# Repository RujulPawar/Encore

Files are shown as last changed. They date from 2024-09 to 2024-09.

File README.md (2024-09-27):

## **Buck Converter Design and Simulation**

### **Team Information**
- **Team Leader**:
  - Rujul Pawar
- **Team Members**: 
  - Samar Mhetre

### **Project Overview**
This repository is for the **Encore Pre-qualifier Challenge 2024-25**, focusing on designing a **buck converter**. The main objectives of this project are:
- **Input Voltage**: 24V DC (1A max)
- **Output Voltage**: 5V DC
- **Target Efficiency**: 90% or higher

### **Repository Structure**
- **Datasheets/**: Relevant component datasheets.
- **KicadFiles/**: Schematic and PCB layout files created using **KiCad**.
- **BuckConverterLtspice.asc**: LTSpice simulation file for testing the design.
- **EncoreBom.csv**: Bill of Materials (BoM) detailing components used.

### **Simulation and PCB Design**
- **Simulation**: To verify the circuit, open and run `BuckConverterLtspice.asc` in **LTSpice**.
- **PCB Layout**: A dual-layer PCB design with a maximum size of **10cm x 5cm**, created using **KiCad**.

### **References**
- [Texas Instruments SLVA477B Design Guide](https://www.ti.com/lit/an/slva477b/slva477b.pdf)

---

This document serves as a concise guide to the contents and structure of this repository. For further details, explore the files and links provided.

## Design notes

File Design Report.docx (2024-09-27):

Design Report

1) Given data:
- V(out) = 5V
- V(in) = 24V
- I(in) = 1A
- Therefore, calculating P(in) = V x I

= 24W

- Required efficiency = 90%
- Therefore, P(out) = 0.9 x 24

= 21.6W

- Calculating output current, I(out) = P(out)/V = 4.32A
2) Assumptions:
- The switching frequency, fs, of a buck converter tends to be higher for minimizing the L and C values. On the other hand, the efficiency of the converter is inversely proportional to the fs, therefore we have chosen a switching frequency fs = 100kHz.
- In an ideal scenario, we assume average voltage across inductor to be zero.
- Similarly, we assume average current through capacitor to be zero.

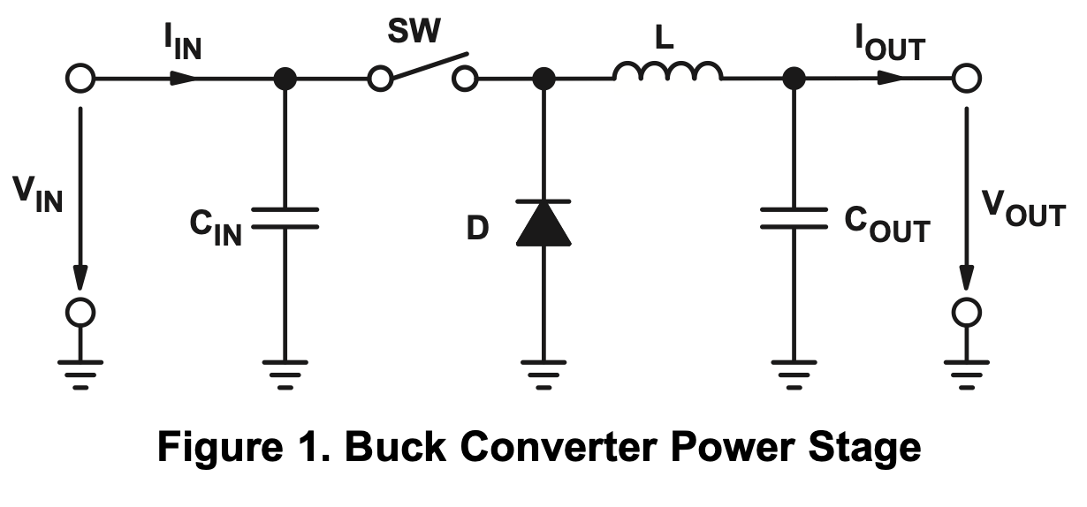
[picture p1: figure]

3) Calculations:
- Based on the above given data and the assumptions made for designing, we have calculated the following values:
  - D = (Vout)/(Vin) = 21%
  - ΔIl = 15% of I(out) = 0.648A
  - Lcritical = ((Vin – Vout) × D)/(2 × Ilb) = 4.4µH

Where Ilb is boundary current through Inductor, which is 4.32A in our case(considering the input current and voltage as 24V)

  - Lripple = (Vin × D × (1-D))/(fs × Il) = 60µH
  - We have to consider the value of L greater than Lripple and Lcritical. Therefore, we have considered L = 75µH.
  - Rpeak = (Vout)/(Iout)=1.15
  - ΔVc = 2% of Vo(peak) … as given in the statement

= 0.1V

  - C = (Vin × D × (1-D))/(8 × fs^2 × Vc) = 6.5µF.
4) Generating 21% duty cycle
- We have used IC 555 to generate the 20% duty cycle for PWM switching.
- Since the astable mode does not allow duty cycle < 50%, we have generated 79% duty cycle using the IC 555 and then used a combination of MOSFETs to reverse the Ton and Toff for the converter circuit, ultimately giving us a Power stage duty cycle of 21% for the converter circuit.
- Calculations for Astable Multivibrator:

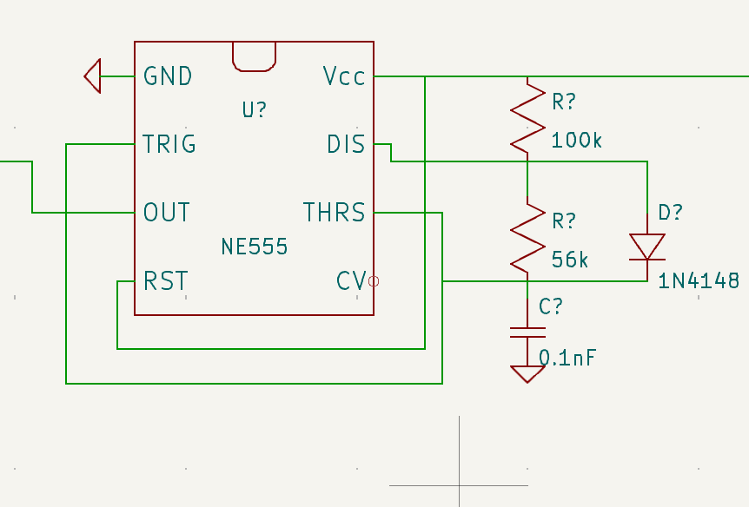
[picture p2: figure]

  - C = 0.1 nF
  - f = 100 kHz
  - Using the above parameters in the equations for astable multivibrator, we got the following values for R1 and R2:
  - R1 = 100 kΩ & R2 = 56 kΩ
  - The values of the resistors were slightly altered to compensate for the losses due to internal components.
  - We ultimately got a duty cycle of 26% for the PWM switching on the buck converter circuit.

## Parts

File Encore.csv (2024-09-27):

Reference | Value | Datasheet | Footprint | Qty | DNP
C1 | 6.6µ |  | Capacitor_SMD:CP_Elec_3x5.3 | 1
C2 | 0.1nF |  | Capacitor_SMD:CP_Elec_3x5.3 | 1
D1 | D |  | Diode_SMD:D_0201_0603Metric | 1
D2 | 1N4148 |  | Diode_SMD:D_0201_0603Metric | 1
L1 | 100µ |  | Inductor_THT:L_Axial_L5.0mm_D3.6mm_P10.00mm_Horizontal_Murata_BL01RN1A2A2 | 1
M1,M2 | BSZ065N06LS5 |  | Package_DirectFET:DirectFET_L4 | 2
R2 | 100k |  | Resistor_SMD:R_0201_0603Metric | 1
R3 | 56k |  | Resistor_SMD:R_0201_0603Metric | 1
R4 | 1k |  | Resistor_SMD:R_0201_0603Metric | 1
ROUT1 | 1.15 |  | Resistor_SMD:R_0201_0603Metric | 1
U1 | NE555 |  | Package_SO:SOIC-8_3.9x4.9mm_P1.27mm | 1
V1 | 24v |  | TerminalBlock_MetzConnect:TerminalBlock_MetzConnect_Type011_RT05502HBWC_1x02_P5.00mm_Horizontal | 1
V2 | 5 |  | TerminalBlock_MetzConnect:TerminalBlock_MetzConnect_Type011_RT05502HBWC_1x02_P5.00mm_Horizontal | 1

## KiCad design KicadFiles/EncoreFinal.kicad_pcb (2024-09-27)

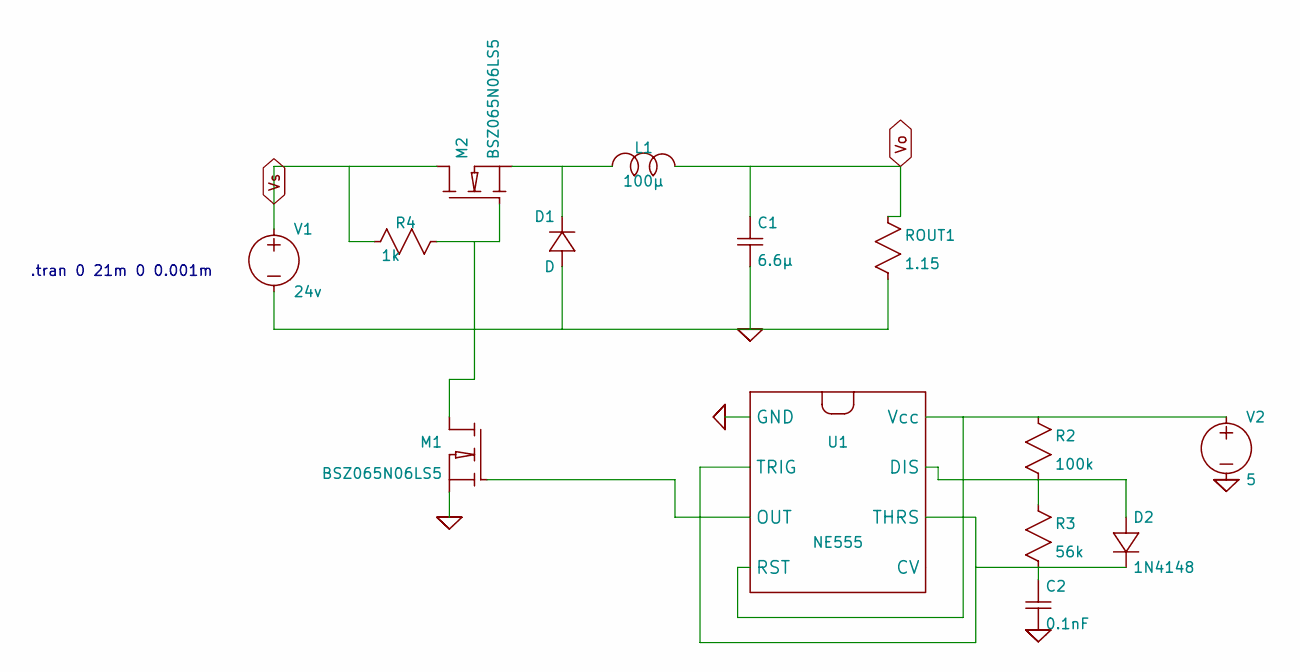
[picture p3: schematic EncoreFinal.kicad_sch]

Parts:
C1: 6.6µ; CP_Elec_3x5.3
C2: 0.1nF; CP_Elec_3x5.3
D1: D; D_0201_0603Metric
D2: 1N4148; D_0201_0603Metric
L1: 100µ; L_Axial_L5.0mm_D3.6mm_P10.00mm_Horizontal_Murata_BL01RN1A2A2
M1, M2: BSZ065N06LS5; DirectFET_L4
R2: 100k; R_0201_0603Metric
R3: 56k; R_0201_0603Metric
R4: 1k; R_0201_0603Metric
ROUT1: 1.15; R_0201_0603Metric
U1: NE555; SOIC-8_3.9x4.9mm_P1.27mm
V1: 24v; TerminalBlock_MetzConnect_Type011_RT05502HBWC_1x02_P5.00mm_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
V2: 5; TerminalBlock_MetzConnect_Type011_RT05502HBWC_1x02_P5.00mm_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

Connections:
0: C1.2, C2.2, D1.1 (+), M1.3 (S), ROUT1.2, U1.1 (GND), V1.2 (-), V2.2 (-)
unnamed: D1.2 (-), L1.1, M2.3 (S)
unnamed: D2.1 (+), R2.2, R3.1, U1.7 (DIS)
unnamed: C2.1, D2.2 (-), R3.2, U1.2 (TRIG), U1.6 (THRS)
unnamed: M1.1 (D), M2.2 (G), R4.1
unnamed: M1.2 (G), U1.3 (OUT)
unnamed: R2.1, U1.4 (RST), U1.8 (Vcc), V2.1 (+)
Vo: C1.1, L1.2, ROUT1.1
Vs: M2.1 (D), R4.2, V1.1 (+)

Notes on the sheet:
.tran 0 21m 0 0.001m

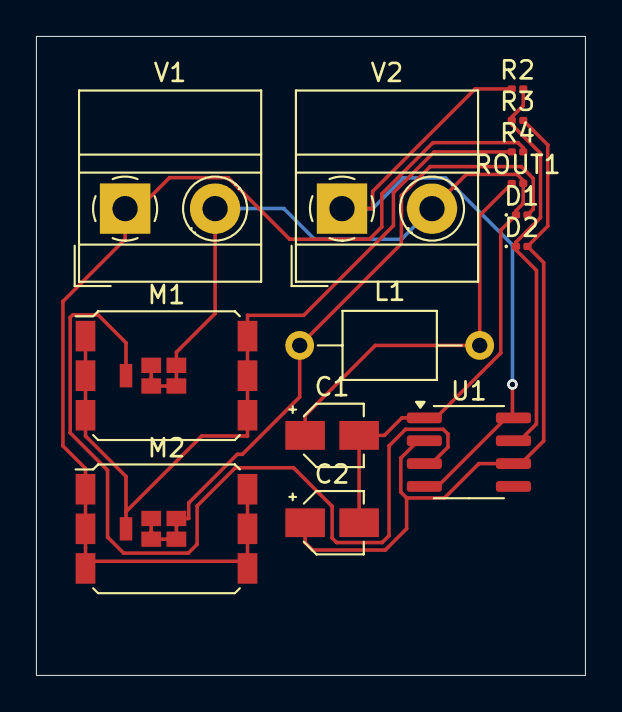
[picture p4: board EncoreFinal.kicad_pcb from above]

Board: 2 copper layers, 30.5 x 35.5 mm, 14 parts (0 on the bottom side), 9 nets.
